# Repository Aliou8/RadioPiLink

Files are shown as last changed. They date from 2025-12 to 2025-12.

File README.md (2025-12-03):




# RadioPiLink

RadioPiLink est un projet IoT permettant la transmission de données radio depuis un microcontrôleur STM32WLE5 vers un Raspberry Pi, puis leur relais sur un réseau local pour traitement et visualisation.

## Table des matières
- [Fonctionnalités](#fonctionnalités)
- [Architecture](#architecture)
- [Licence](#licence)

## Fonctionnalités
- Réception radio sur STM32WLE5
- Passerelle vers Raspberry Pi
- Routage des données vers le réseau local
- Points d'extension pour traitement et visualisation

## Architecture

Consultez :
* [meta-radiopilink](meta-radiopilink/README.md)
* [hardware](hardware/README.md)
* [software](software/README.md)

## Licence
Ce projet est distribué sous la licence GNU GPL v3. Voir le fichier LICENSE pour les détails.

## Contact
Pour toute question ou contribution, ouvrez une issue ou contactez les mainteneurs via la page du dépôt.

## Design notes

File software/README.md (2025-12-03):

software
=================

Description
-----------
Ce dossier contient le programme necessaire pour faire fonctionner la carte STM32. Le projet utilise cmake et support que le micro STM32WLE5 pour lutiliser avec une autre version de microcontoleur il faut veiller a respecter le BSP pour des fonction comme :

Dépendances
-----------
- cmake
- ninja ou make pour compiler

Structure
---------

Licence
-------
Voir le fichier LICENSE à la racine du dépôt pour les détails de licence.

Contact
-------
Pour questions ou rapports de bugs, ouvrez une issue dans le dépôt GitHub du projet.

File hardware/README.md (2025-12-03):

La carte est basée sur un STM32WLE5CCU6 dont la particularité est d'embarquer directement un module sub‑radio.

* Radio
    * **Plage de fréquence :** 150 MHz à 960 MHz
    * **Modulation :** LoRa®, (G)FSK, (G)MSK et BPSK
    * **Sensibilité RX :** –123 dBm pour 2-FSK (à 1,2 Kbit/s), –148 dBm pour LoRa® (à 10,4 kHz, facteur d'étalement 12)
    * **Puissance de sortie élevée du transmetteur :** programmable jusqu'à +22 dBm
    * **Puissance de sortie faible du transmetteur :** programmable jusqu'à +15 dBm

Le design actuel ne fonctionne qu'avec des fréquences et des puissances élevées, mais les versions suivantes permettront de mettre en place des commutateurs RF et des commutateurs d'alimentation pour choisir entre **HP/LP** et **HF/LF**.

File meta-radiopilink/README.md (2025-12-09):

meta-radiopilink
=================

Description
-----------
meta-radiopilink est une couche Yocto/OpenEmbedded fournissant les recettes,
configurations et fichiers nécessaires pour construire une image Linux adaptée
au projet RadioPiLink (daemon, configurations et tools spécifiques).

Dépendances
-----------
- Yocto Project / Poky 
- bitbake
- meta-raspberrypi 
- autres layers requis listés dans conf/layer.conf

Installation rapide
-------------------
1. Placez la couche dans votre répertoire de sources Yocto (ex: poky/sources) :
  ```bash
  git clone <repo-meta-radiopilink> meta-radiopilink
  ```
2. Ajoutez la couche à bblayers dans conf/bblayers.conf :
    meta-radiopilink
    
3. Dans conf/local.conf, définissez la MACHINE appropriée et ajoutez toute
    variable spécifique au projet .
  ```bash
    IMAGE_INSTALL:append = " radiopilink "
    DISTRO = "radiopilinkdistro"
  ```

Construction
-----------
Exemples de commandes depuis l'environnement Yocto (après avoir sourcé oe-init-build-env) :

- Construire une image minimale :
  bitbake core-image-minimal

- Construire l'image RadioPiLink fournie :
  ```bash
    bitbake radiopilink-image
  ```

Déploiement
----------
Après construction, récupérez l'image générée dans tmp/deploy/images/<MACHINE>.
Pour flasher une carte SD (exemple avec dd) :

  ```bash
  sudo dd if=<image>.sdimg of=/dev/sdX bs=4M conv=fsync
  ```

Remarques de debug
------------------
- Consulter les logs de bitbake (tmp/work/.../temp/log.do_configure, etc.)
- Monter l'image rootfs pour inspecter /etc, /usr/bin et les services
- Activer systemd journal sur la cible pour voir les erreurs du daemon

Structure de la couche
----------------------

Licence
-------
Voir le fichier LICENSE à la racine du dépôt pour les détails de licence.

Contact
-------
Pour questions ou rapports de bugs, ouvrez une issue dans le dépôt GitHub du projet.

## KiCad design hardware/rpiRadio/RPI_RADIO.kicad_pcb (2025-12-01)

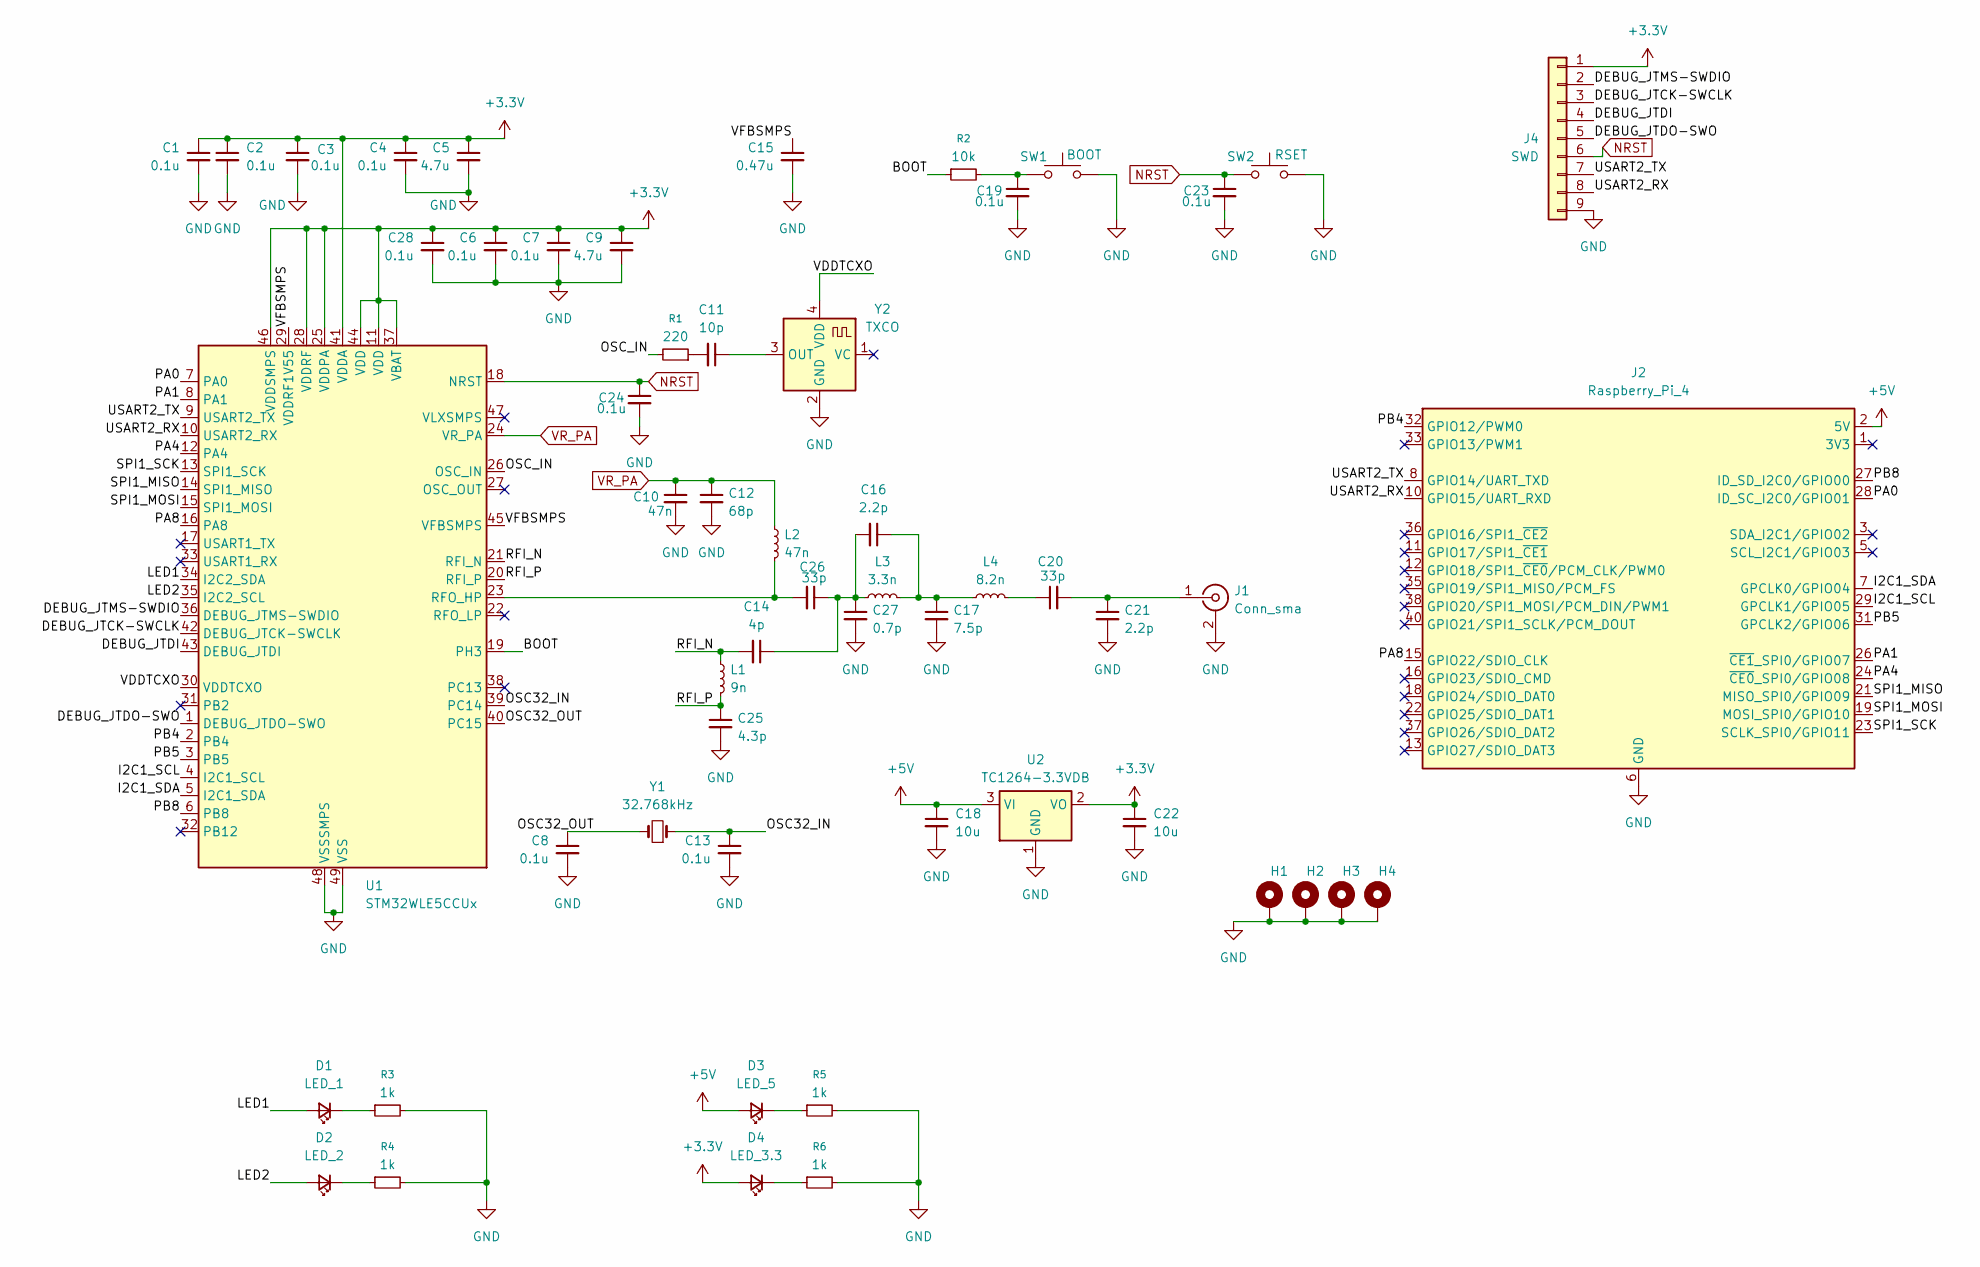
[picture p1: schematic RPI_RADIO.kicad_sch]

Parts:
C1, C2, C3, C4, C6, C7, C8, C13, C19, C23, C24, C28: 0.1u; C_0603_1608Metric
C5, C9: 4.7u; C_0603_1608Metric
C10: 47n; C_0603_1608Metric
C11: 10p; C_0603_1608Metric
C12: 68p; C_0603_1608Metric
C14: 4p; C_0603_1608Metric
C15: 0.47u; C_0603_1608Metric
C16, C21: 2.2p; C_0603_1608Metric
C17: 7.5p; C_0603_1608Metric
C18, C22: 10u; C_0805_2012Metric
C20, C26: 33p; C_0603_1608Metric
C25: 4.3p; C_0603_1608Metric
C27: 0.7p; C_0603_1608Metric
D1: LED_1; LED_0603_1608Metric
D2: LED_2; LED_0603_1608Metric
D3: LED_5; LED_0603_1608Metric
D4: LED_3.3; LED_0603_1608Metric
H1, H2, H3, H4: MountingHole_Pad; MountingHole_2.5mm_Pad
J1: Conn_sma; SMA_Amphenol_132289_EdgeMount
J2: Raspberry_Pi_4; PinSocket_2x20_P2.54mm_Vertical
J4: SWD; PinHeader_1x09_P2.54mm_Vertical
L1: 9n; L_0402_1005Metric
L2: 47n; L_0603_1608Metric
L3: 3.3n; L_0603_1608Metric
L4: 8.2n; L_0603_1608Metric
R1: 220; R_0603_1608Metric
R2: 10k; R_0603_1608Metric
R3, R4, R5, R6: 1k; R_0603_1608Metric
SW1: BOOT; SW_Push_1P1T_NO_CK_KMR2
SW2: RSET; SW_Push_1P1T_NO_CK_KMR2
U1: STM32WLE5CCUx; QFN-48-1EP_7x7mm_P0.5mm_EP5.6x5.6mm
U2: TC1264-3.3VDB; SOT-223-3_TabPin2
Y1: 32.768kHz; Crystal_SMD_3215-2Pin_3.2x1.5mm
Y2: TXCO; Oscillator_SMD_SeikoEpson_SG8002CE-4Pin_3.2x2.5mm

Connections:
+3.3V: C1.1, C2.1, C3.1, C4.1, C5.1, C6.1, C7.1, C9.1, C22.1, C28.1, D4.2 (A), J4.1, U1.11 (VDD), U1.25 (VDDPA), U1.28 (VDDRF), U1.37 (VBAT), U1.41 (VDDA), U1.44 (VDD), U1.46 (VDDSMPS), U2.2 (VO)
+5V: C18.1, D3.2 (A), J2.2 (5V), J2.4 (5V), U2.3 (VI)
/BOOT: R2.1, U1.19 (PH3)
/DEBUG_JTCK-SWCLK: J4.3, U1.42 (DEBUG_JTCK-SWCLK)
/DEBUG_JTDI: J4.4, U1.43 (DEBUG_JTDI)
/DEBUG_JTDO-SWO: J4.5, U1.1 (DEBUG_JTDO-SWO)
/DEBUG_JTMS-SWDIO: J4.2, U1.36 (DEBUG_JTMS-SWDIO)
/I2C1_SCL: J2.29 (GPCLK1/GPIO05), U1.4 (I2C1_SCL)
/I2C1_SDA: J2.7 (GPCLK0/GPIO04), U1.5 (I2C1_SDA)
/LED1: D1.2 (A), U1.34 (I2C2_SDA)
/LED2: D2.2 (A), U1.35 (I2C2_SCL)
/OSC32_IN: C13.1, U1.39 (PC14), Y1.1
/OSC32_OUT: C8.1, U1.40 (PC15), Y1.2
/OSC_IN: R1.2, U1.26 (OSC_IN)
/PA0: J2.28 (ID_SC_I2C0/GPIO01), U1.7 (PA0)
/PA1: J2.26 (~CE1_SPI0/GPIO07), U1.8 (PA1)
/PA4: J2.24 (~CE0_SPI0/GPIO08), U1.12 (PA4)
/PA8: J2.15 (GPIO22/SDIO_CLK), U1.16 (PA8)
/PB4: J2.32 (GPIO12/PWM0), U1.2 (PB4)
/PB5: J2.31 (GPCLK2/GPIO06), U1.3 (PB5)
/PB8: J2.27 (ID_SD_I2C0/GPIO00), U1.6 (PB8)
/RFI_N: C14.2, L1.1, U1.21 (RFI_N)
/RFI_P: C25.1, L1.2, U1.20 (RFI_P)
/SPI1_MISO: J2.21 (MISO_SPI0/GPIO09), U1.14 (SPI1_MISO)
/SPI1_MOSI: J2.19 (MOSI_SPI0/GPIO10), U1.15 (SPI1_MOSI)
/SPI1_SCK: J2.23 (SCLK_SPI0/GPIO11), U1.13 (SPI1_SCK)
/USART2_RX: J2.10 (GPIO15/UART_RXD), J4.8, U1.10 (USART2_RX)
/USART2_TX: J2.8 (GPIO14/UART_TXD), J4.7, U1.9 (USART2_TX)
/VDDTCXO: U1.30 (VDDTCXO), Y2.4 (VDD)
/VFBSMPS: C15.1, U1.29 (VDDRF1V55), U1.45 (VFBSMPS)
GND: C1.2, C2.2, C3.2, C4.2, C5.2, C6.2, C7.2, C8.2, C9.2, C10.2, C12.2, C13.2, C15.2, C17.2, C18.2, C19.2, C21.2, C22.2, C23.2, C24.2, C25.2, C27.2, C28.2, H1.1, H2.1, H3.1, H4.1, J1.2 (Ext), J2.6 (GND), J2.9 (GND), J2.14 (GND), J2.20 (GND), J2.25 (GND), J2.30 (GND), J2.34 (GND), J2.39 (GND), J4.9, R3.2, R4.2, R5.2, R6.2, SW1.2, SW2.2, U1.48 (VSSSMPS), U1.49 (VSS), U2.1 (GND), Y2.2 (GND)
NRST: C23.1, C24.1, J4.6, SW2.1, U1.18 (NRST)
unnamed: C11.2, R1.1
unnamed: C14.1, C16.2, C26.1, C27.1, L3.1
unnamed: C16.1, C17.1, L3.2, L4.1
unnamed: C19.1, R2.2, SW1.1
unnamed: C20.1, L4.2
unnamed: D1.1 (K), R3.1
unnamed: D2.1 (K), R4.1
unnamed: D3.1 (K), R5.1
unnamed: D4.1 (K), R6.1
unnamed: C20.2, C21.1, J1.1 (In)
unnamed: C26.2, L2.2, U1.23 (RFO_HP)
unnamed: C11.1, Y2.3 (OUT)
VR_PA: C10.1, C12.1, L2.1, U1.24 (VR_PA)

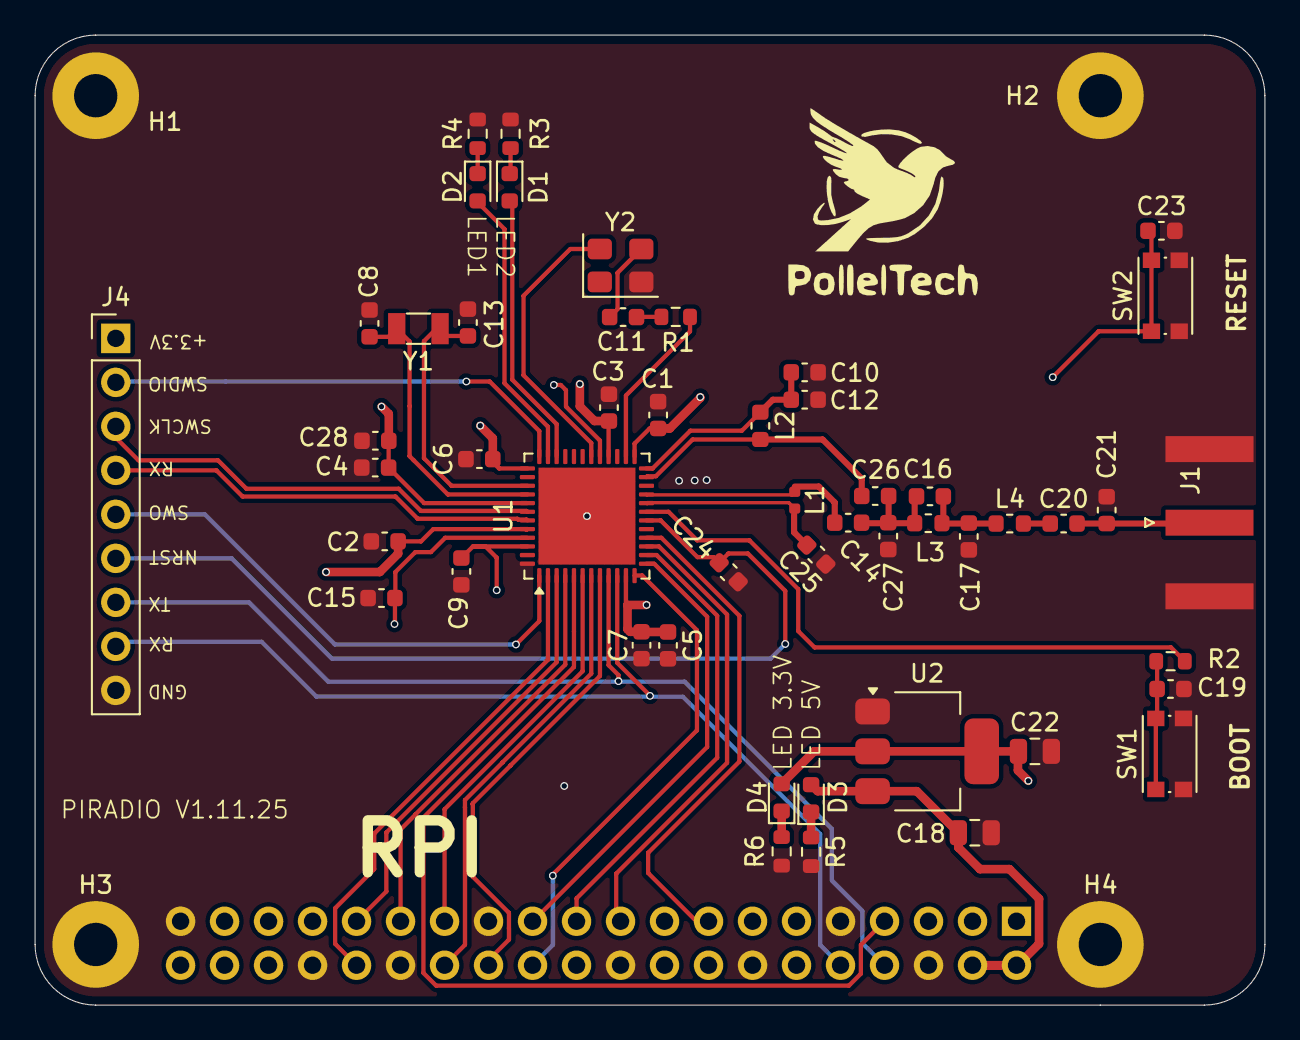
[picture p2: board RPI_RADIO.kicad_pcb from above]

Board: 4 copper layers, 71.0 x 56.0 mm, 55 parts (1 on the bottom side), 45 nets.

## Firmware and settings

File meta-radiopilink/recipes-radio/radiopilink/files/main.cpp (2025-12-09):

#include <iostream>
#include <cstring>
#include <fcntl.h>
#include <sys/ioctl.h>
#include <linux/spi/spidev.h>
#include <unistd.h>
#include <stdint.h>

int main() {
    const char* device = "/dev/spidev0.0";

    // --- 1. Ouvrir le device SPI ---
    int fd = open(device, O_RDWR);
    if (fd < 0) {
        perror("Erreur open spidev");
        return 1;
    }

    // --- 2. Paramètres SPI ---
    uint8_t mode = SPI_MODE_0;
    uint8_t bits = 8;
    uint32_t speed = 1'000'000; // 1 MHz

    ioctl(fd, SPI_IOC_WR_MODE, &mode);
    ioctl(fd, SPI_IOC_WR_BITS_PER_WORD, &bits);
    ioctl(fd, SPI_IOC_WR_MAX_SPEED_HZ, &speed);

    // --- 3. Préparer buffers ---
    uint8_t tx[] = { 0x9F };  // Exemple : commande JEDEC ID
    uint8_t rx[3] = { 0, 0, 0 };

    // Structure spi_ioc_transfer
    struct spi_ioc_transfer tr = {};
    tr.tx_buf = (unsigned long)tx;
    tr.rx_buf = (unsigned long)rx;
    tr.len = sizeof(tx) + sizeof(rx);     // nombre total d’octets
    tr.speed_hz = speed;
    tr.bits_per_word = bits;

    // --- 4. Appeler ioctl SPI ---
    int ret = ioctl(fd, SPI_IOC_MESSAGE(1), &tr);
    if (ret < 1) {
        perror("Erreur transfert SPI");
        return 1;
    }

    // --- 5. Afficher ce qu’on a reçu ---
    std::cout << "Reçu : ";
    for (int i = 0; i < sizeof(rx); i++)
        std::cout << std::hex << (int)rx[i] << " ";
    std::cout << std::dec << std::endl;

    close(fd) ; 
    return 0;
}

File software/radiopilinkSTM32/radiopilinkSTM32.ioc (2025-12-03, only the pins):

Mcu.UserName=STM32WLE5CCUx
PA0.GPIO_Label=PA0
PA0.Signal=GPIO_Output
PA1.GPIO_Label=PA1
PA1.Signal=GPIO_Output
PA11.GPIO_Label=LED1
PA11.Signal=GPIO_Output
PA12.GPIO_Label=LED2
PA12.Signal=GPIO_Output
PA13.Signal=DEBUG_JTMS-SWDIO
PA14.Signal=DEBUG_JTCK-SWCLK
PA15.Signal=DEBUG_JTDI
PA2.Signal=USART2_TX
PA3.Signal=USART2_RX
PA4.GPIO_Label=PA4
PA4.Signal=GPIO_Output
PA5.Signal=SPI1_SCK
PA6.Signal=SPI1_MISO
PA7.Signal=SPI1_MOSI
PA8.GPIO_Label=PA8
PA8.Signal=GPIO_Analog
PB0-VDD_TCXO.Signal=VDDTCXO
PB3.Signal=DEBUG_JTDO-SWO
PB4.GPIO_Label=PB4
PB4.Signal=GPIO_Output
PB5.GPIO_Label=PB5
PB5.Signal=GPIO_Output
PB6.Signal=I2C1_SCL
PB7.Signal=I2C1_SDA
PB8.GPIO_Label=PB8
PB8.Signal=GPIO_Output
PC14-OSC32_IN.Signal=RCC_OSC32_IN
PC15-OSC32_OUT.Signal=RCC_OSC32_OUT

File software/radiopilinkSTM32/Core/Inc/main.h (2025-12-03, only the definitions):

#define PB4_Pin GPIO_PIN_4
#define PB4_GPIO_Port GPIOB
#define PB5_Pin GPIO_PIN_5
#define PB5_GPIO_Port GPIOB
#define PB8_Pin GPIO_PIN_8
#define PB8_GPIO_Port GPIOB
#define PA0_Pin GPIO_PIN_0
#define PA0_GPIO_Port GPIOA
#define PA1_Pin GPIO_PIN_1
#define PA1_GPIO_Port GPIOA
#define PA4_Pin GPIO_PIN_4
#define PA4_GPIO_Port GPIOA
#define PA8_Pin GPIO_PIN_8
#define PA8_GPIO_Port GPIOA
#define LED1_Pin GPIO_PIN_11
#define LED1_GPIO_Port GPIOA
#define LED2_Pin GPIO_PIN_12
#define LED2_GPIO_Port GPIOA

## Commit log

2025-12-01 Ajout de hard and pcb
    [RPI_RADIO.kicad_pcb, RPI_RADIO.kicad_sch]
2025-12-03 STM32 soft
2025-12-03 Correction des README
2025-12-03 Correction du README de meta-radiopilink
2025-12-09 Avan sur linux yocto 1
    [RPI_RADIO.kicad_sch, kernelconfig.cfg]
2025-12-09 Correction de la commande de construction de l'image RadioPiLink dans le README

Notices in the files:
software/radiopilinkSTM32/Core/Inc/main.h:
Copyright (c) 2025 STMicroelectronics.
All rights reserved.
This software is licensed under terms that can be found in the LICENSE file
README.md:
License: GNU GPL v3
